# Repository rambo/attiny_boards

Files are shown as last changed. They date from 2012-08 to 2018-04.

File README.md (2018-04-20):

View this project on [CADLAB.io](https://cadlab.io/node/904). 

# ATTiny breakout boards

Collection of various more or less prototype board designs for breaking
out SMD ATTinys.

The SMD parts are cheaper than DIP and I've grown tired of drilling holes
anyway, besides this way I can add some essential supporting hardware like
bypass caps and the ISP header on the same board (optionally also xtal)

Arduino support for these chips is available from the [arduino-tiny](https://github.com/rambo/arduino-tiny) project, 
see also [this tutorial](http://hlt.media.mit.edu/?p=1695) by High-Low Tech.

I personally have found using the ArduinoISP a bit hit-and-miss, so I suggest investing on a proper ISP (some of the clones work better
than others but I decided to get a genuine AVRISPmkII after spending an evening battling with ArduinoISP)

## The designs

  - attiny85_bo_1l.brd: this is a very quick design for ATTiny25/45/85 chips meant to be etched at home, thus in one layer. [Picture](https://picasaweb.google.com/lh/photo/0eMphjL9Uqn8iMIKu49FZNMTjNZETYmyPJy0liipFm0?feat=directlink).
  - attiny85_bo.brd: A two-layer design for ATTiny25/45/85 chips that should be generally quite usable. [Picture](https://picasaweb.google.com/lh/photo/wWMrBrGMo7IKX4xKiI6fBtMTjNZETYmyPJy0liipFm0?feat=directlink).
    - First revisions of the board had a silkscreen error, PB1 and PB2 were reversed (my bad).
    - For some reason the very first revision has much nicer silkscreen than the next, they were (likely) manufactured in different batches but I should doublecheck line widths etc.
  - attiny4313_bo.brd: A two-layer design (with a lot of vias so not really doable at home).
    - Got the boards, silkscreen is fine on these, [picture](https://picasaweb.google.com/lh/photo/29UdsFFLtWyybYlaUJ8i69MTjNZETYmyPJy0liipFm0?feat=directlink).
  - attiny84_bo.brd: A two-layer design that should be generally quite usable.
    - Got the boards, silkscreen is fine on these, [picture](https://picasaweb.google.com/lh/photo/29UdsFFLtWyybYlaUJ8i69MTjNZETYmyPJy0liipFm0?feat=directlink).
  - attiny1634_bo.brd: First revision of this board/schematic had a bug in the part definition. Thus a [trace must be cut](https://picasaweb.google.com/lh/photo/p4AA6TQTbEzGxg4LxbUNLtMTjNZETYmyPJy0liipFm0?feat=directlink) and a jumper wire added.
    - arduino-tiny support for this chip is still [experimental](https://github.com/rambo/arduino-tiny/tree/attiny1634)
  - attiny85_pogo_pgm.brd: an attempt to make a pogo-pin programming header that connects directly to ATTiny85 (SOIC) feet.
    - This proved to be rather misguided, it will require very carefull alignment rig but if I get the need of mass programming unsoldered chips I might still do it.

## TODO

  - Add diodes to protect against reverse and over -voltage (with indicator led ?)
  - simple board to break the ISP header into normal 2.54mm pitch pogo-pins in the same order (those pins unfortunately do not fit)
    into the cable connector directly), did this on stripboard and then realized dotboard would have been much better.

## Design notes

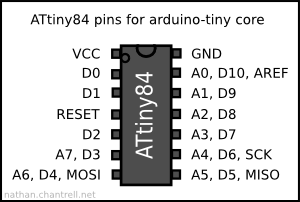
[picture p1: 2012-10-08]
attiny84_arduino_pins.png

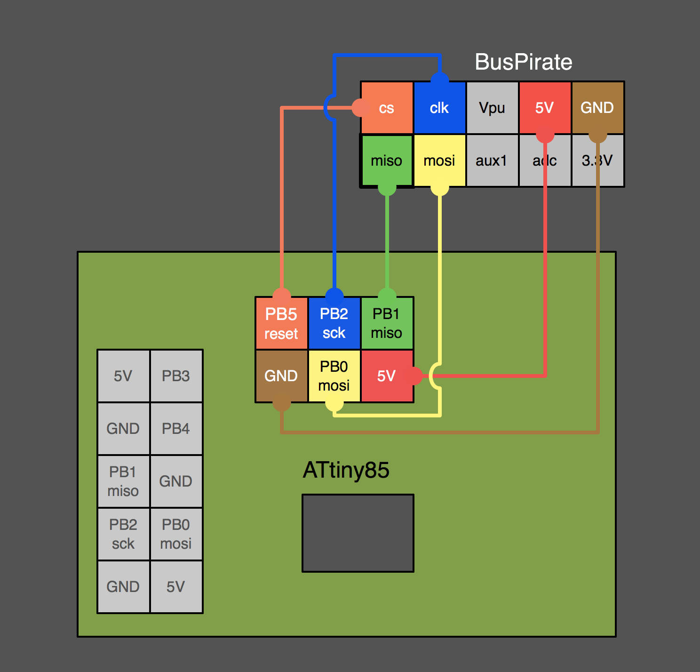
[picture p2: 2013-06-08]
buspirate_as_isp.png

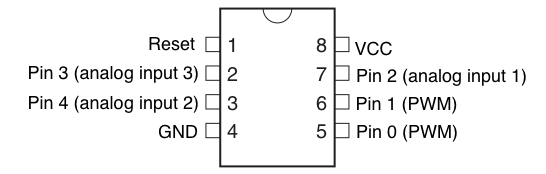
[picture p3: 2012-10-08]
attiny85_arduino_pins.png

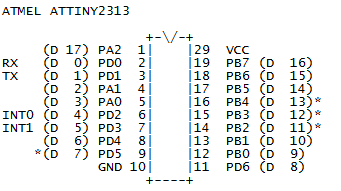
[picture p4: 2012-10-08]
attiny2313_arduino_pins.png

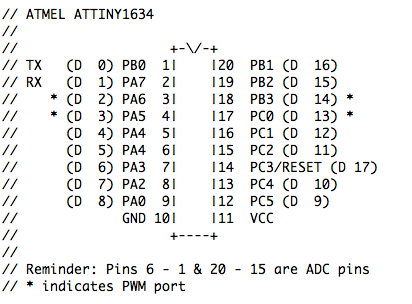
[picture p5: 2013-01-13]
attiny1634_arduino_pins.png

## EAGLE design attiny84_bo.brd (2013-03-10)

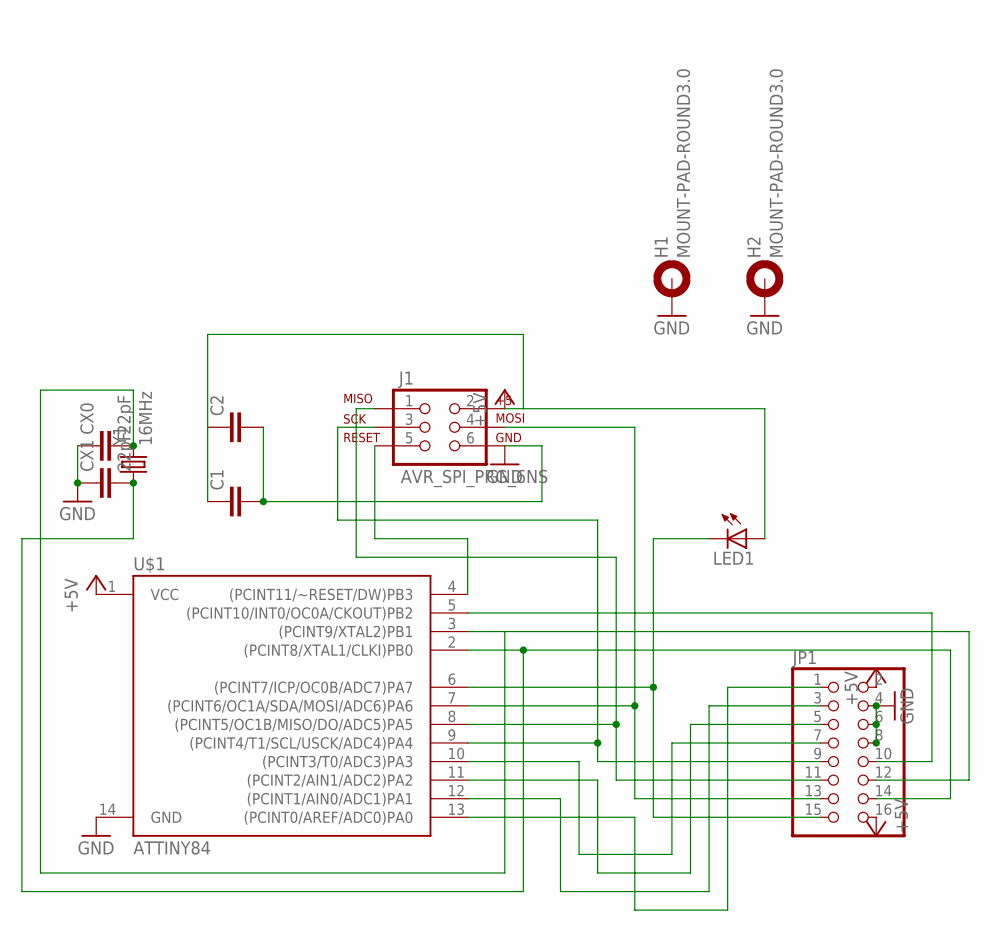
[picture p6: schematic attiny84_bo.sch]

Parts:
C1, C2: C-EUC0805; C0805
CX0, CX1: 22pF; C0603
H1, H2: MOUNT-PAD-ROUND3.0; 3,0-PAD
J1: AVR_SPI_PRG_6NS; 2X3-NS
JP1: PINHD-2X8; 2X08
LED1: LED0603; LED-0603
U$1: ATTINY84; SO14
Y1: 16MHz; CRYSTAL-SMD-5X3

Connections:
+5V: C1.1, C2.1, J1.2, JP1.2, JP1.16, LED1.A, U$1.1 (VCC)
GND: C1.2, C2.2, CX0.1, CX1.1, H1.B3,0, H2.B3,0, J1.6, JP1.4, JP1.6, JP1.8, U$1.14 (GND)
PA0: JP1.1, U$1.13 ((PCINT0/AREF/ADC0)PA0)
PA1: JP1.3, U$1.12 ((PCINT1/AIN0/ADC1)PA1)
PA2: JP1.5, U$1.11 ((PCINT2/AIN1/ADC2)PA2)
PA3: JP1.7, U$1.10 ((PCINT3/T0/ADC3)PA3)
PA4/SCL: J1.3, JP1.9, U$1.9 ((PCINT4/T1/SCL/USCK/ADC4)PA4)
PA5/MISO: J1.1, JP1.11, U$1.8 ((PCINT5/OC1B/MISO/DO/ADC5)PA5)
PA6/MOSI: J1.4, JP1.13, U$1.7 ((PCINT6/OC1A/SDA/MOSI/ADC6)PA6)
PA7: JP1.15, LED1.C, U$1.6 ((PCINT7/ICP/OC0B/ADC7)PA7)
PB0/XTAL1: CX1.2, JP1.14, U$1.2 ((PCINT8/XTAL1/CLKI)PB0), Y1.1
PB1/XTAL2: CX0.2, JP1.12, U$1.3 ((PCINT9/XTAL2)PB1), Y1.3 (2)
PB2: JP1.10, U$1.5 ((PCINT10/INT0/OC0A/CKOUT)PB2)
PB3/RESET-: J1.5, U$1.4 ((PCINT11/~RESET/DW)PB3)

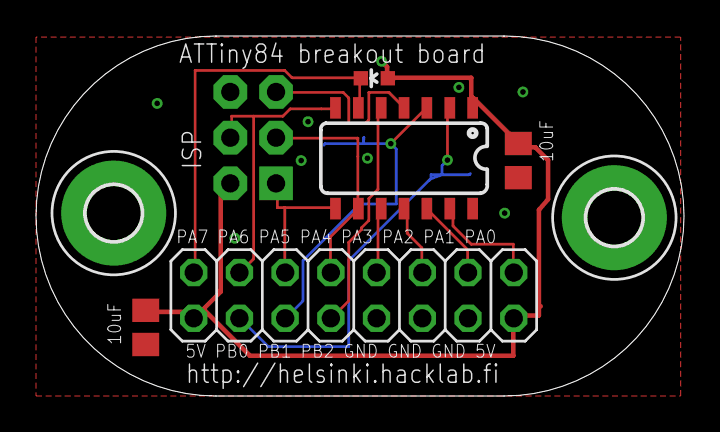
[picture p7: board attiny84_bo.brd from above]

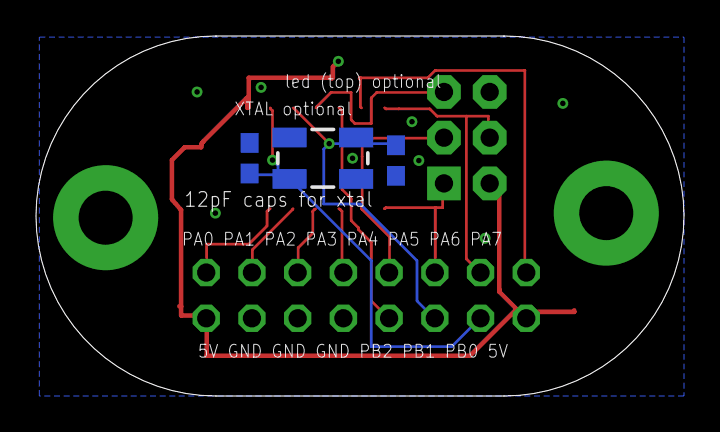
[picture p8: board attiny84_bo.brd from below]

Board: 2 copper layers, 36.0 x 20.0 mm, 11 parts (3 on the bottom side), 14 nets.

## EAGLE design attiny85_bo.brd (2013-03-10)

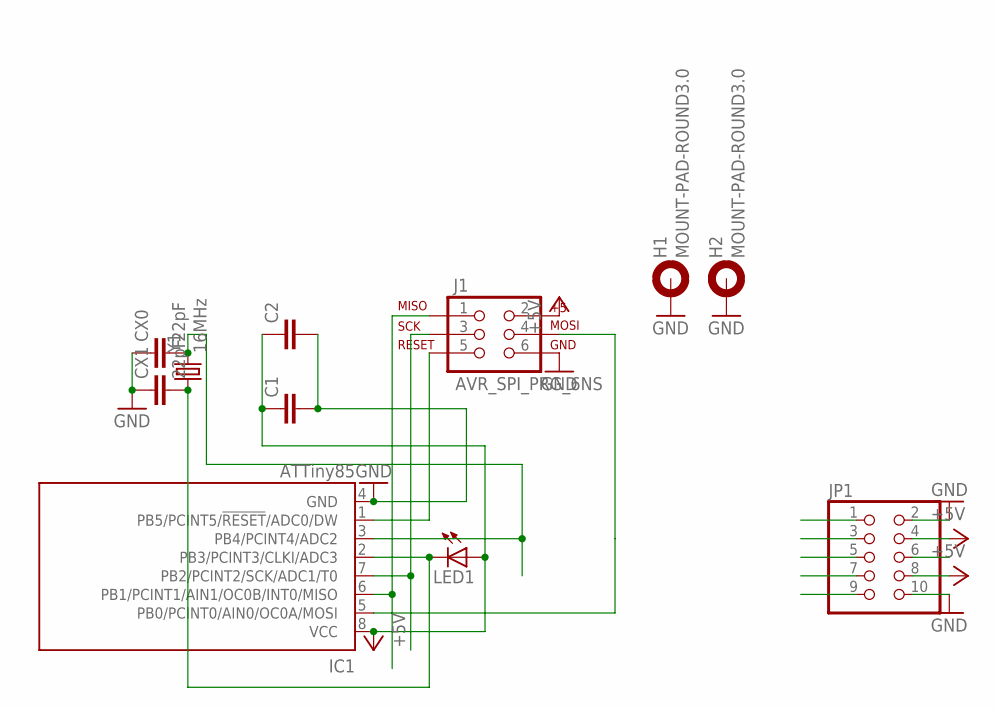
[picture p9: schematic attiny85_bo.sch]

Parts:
C1, C2: C-EUC0805; C0805
CX0, CX1: 22pF; C0603
H1, H2: MOUNT-PAD-ROUND3.0; 3,0-PAD
IC1: ATTiny85; 8S2
J1: AVR_SPI_PRG_6NS; 2X3-NS
JP1: PINHD-2X5; 2X05
LED1: LED0603; LED-0603
Y1: 16MHz; CRYSTAL-SMD-5X3

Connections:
+5V: C1.1, C2.1, IC1.8 (VCC), J1.2, JP1.4, JP1.8, LED1.A
GND: C1.2, C2.2, CX0.1, CX1.1, H1.B3,0, H2.B3,0, IC1.4 (GND), J1.6, JP1.2, JP1.10
PB0: IC1.5 (PB0/PCINT0/AIN0/OC0A/MOSI), J1.4, JP1.1
PB1: IC1.6 (PB1/PCINT1/AIN1/OC0B/INT0/MISO), J1.1, JP1.3
PB2: IC1.7 (PB2/PCINT2/SCK/ADC1/T0), J1.3, JP1.5
PB3: CX1.2, IC1.2 (PB3/PCINT3/CLKI/ADC3), JP1.7, LED1.C, Y1.1
PB4: CX0.2, IC1.3 (PB4/PCINT4/ADC2), JP1.9, Y1.3 (2)
PB5: IC1.1 (PB5/PCINT5/!RESET!/ADC0/DW), J1.5, JP1.6

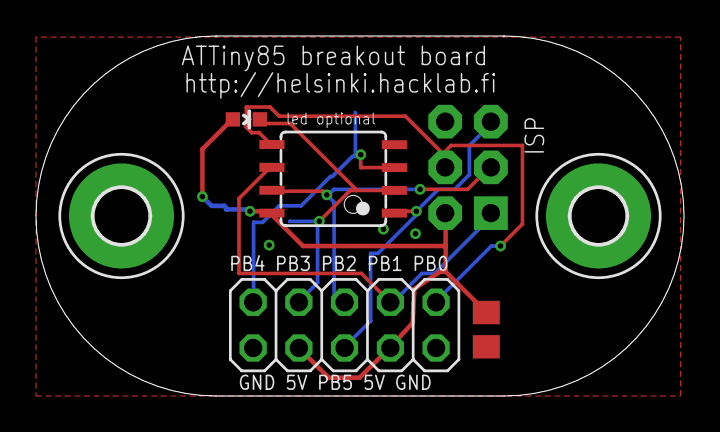
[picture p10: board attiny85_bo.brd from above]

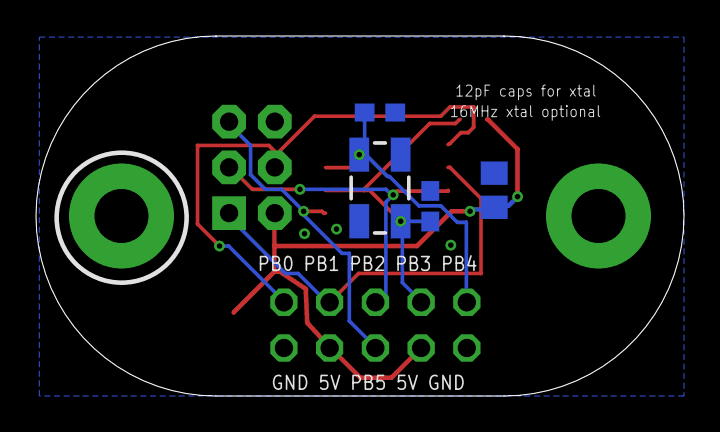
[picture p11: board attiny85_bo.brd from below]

Board: 2 copper layers, 36.0 x 20.0 mm, 11 parts (4 on the bottom side), 8 nets.

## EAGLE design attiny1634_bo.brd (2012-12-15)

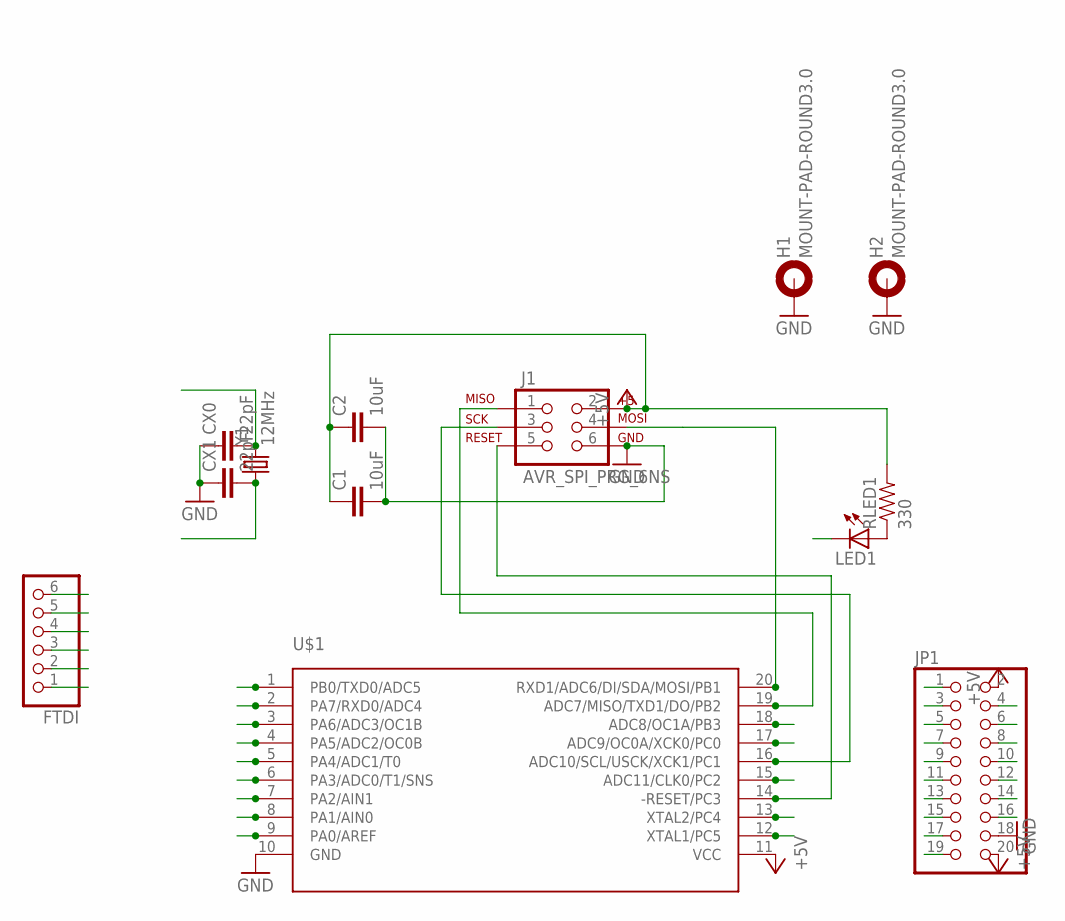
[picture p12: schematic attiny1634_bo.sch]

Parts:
C1, C2: 10uF; C0805
CX0, CX1: 22pF; C0603
FTDI: PINHD-1X6; 1X06
H1, H2: MOUNT-PAD-ROUND3.0; 3,0-PAD
J1: AVR_SPI_PRG_6NS; 2X3-NS
JP1: PINHD-2X10; 2X10
LED1: LED0603; LED-0603
RLED1: 330; 0603-RES
U$1: ATTINY1634; SOIC20
Y1: 12MHz; CRYSTAL-SMD-5X3

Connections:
+5V: C1.1, C2.1, FTDI.3, J1.2, JP1.2, JP1.20, RLED1.2, U$1.11 (VCC)
CTS: FTDI.2
GND: C1.2, C2.2, CX0.1, CX1.1, FTDI.1, H1.B3,0, H2.B3,0, J1.6, JP1.18, U$1.10 (GND)
unnamed: LED1.A, RLED1.1
PA0: JP1.5, U$1.9 (PA0/AREF)
PA1: JP1.7, U$1.8 (PA1/AIN0)
PA2: JP1.9, U$1.7 (PA2/AIN1)
PA3: JP1.11, U$1.6 (PA3/ADC0/T1/SNS)
PA4: JP1.13, U$1.5 (PA4/ADC1/T0)
PA5: JP1.15, U$1.4 (PA5/ADC2/OC0B)
PA6: JP1.17, U$1.3 (PA6/ADC3/OC1B)
PA7/RX0: FTDI.4, JP1.19, U$1.2 (PA7/RXD0/ADC4)
PB0/TXD0: FTDI.5, JP1.16, U$1.1 (PB0/TXD0/ADC5)
PB1/MOSI/ADC6: J1.4, JP1.14, U$1.20 (RXD1/ADC6/DI/SDA/MOSI/PB1)
PB2/ADC7/TX1: J1.1, JP1.12, U$1.19 (ADC7/MISO/TXD1/DO/PB2)
PB3/ADC8/OC1A: JP1.10, U$1.18 (ADC8/OC1A/PB3)
PC0/ADC9/OC0A: JP1.8, LED1.C, U$1.17 (ADC9/OC0A/XCK0/PC0)
PC1/SCL/ADC10: J1.3, JP1.1, U$1.16 (ADC10/SCL/USCK/XCK1/PC1)
PC2/ADC11: JP1.3, U$1.15 (ADC11/CLK0/PC2)
PC3/-RESET: FTDI.6, J1.5, U$1.14 (-RESET/PC3)
PC4/XTAL2: CX0.2, JP1.6, U$1.13 (XTAL2/PC4), Y1.3 (2)
PC5/XTAL1: CX1.2, JP1.4, U$1.12 (XTAL1/PC5), Y1.1

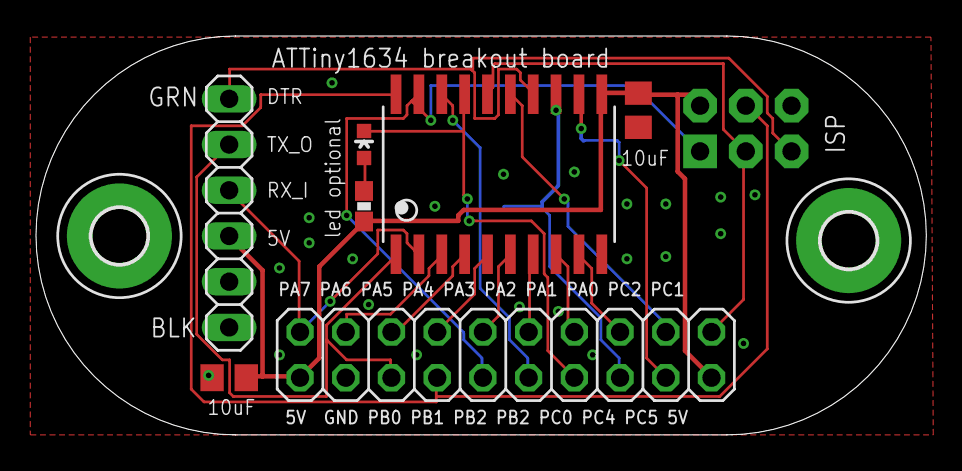
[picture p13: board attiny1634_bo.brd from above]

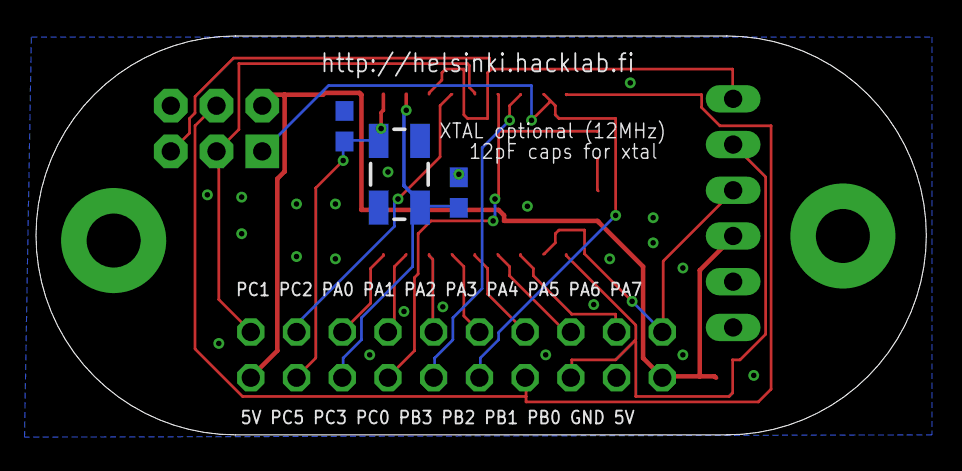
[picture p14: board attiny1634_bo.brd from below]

Board: 2 copper layers, 49.5 x 22.2 mm, 13 parts (3 on the bottom side), 21 nets.

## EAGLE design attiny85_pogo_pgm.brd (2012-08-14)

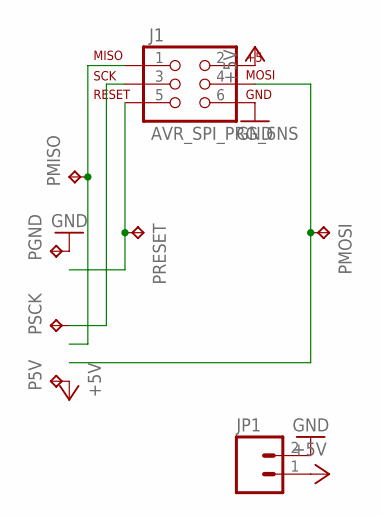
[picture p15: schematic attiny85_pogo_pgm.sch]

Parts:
J1: AVR_SPI_PRG_6NS; 2X3-NS
JP1: M02PTH; 1X02
P5V: TPTP12R; TP12R
PGND: TPTP12R; TP12R
PMISO: TPTP12R; TP12R
PMOSI: TPTP12R; TP12R
PRESET: TPTP12R; TP12R
PSCK: TPTP12R; TP12R

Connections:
+5V: J1.2, JP1.1, P5V.TP
GND: J1.6, JP1.2, PGND.TP
IN1/MISO: J1.1, PMISO.TP
RESET-: J1.5, PRESET.TP
SCL/SCK: J1.3, PSCK.TP
SDA/MOSI: J1.4, PMOSI.TP

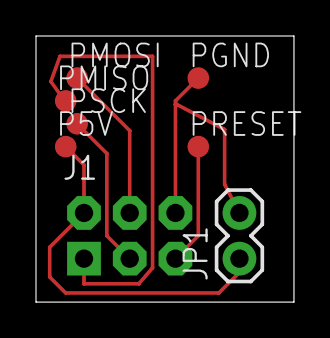
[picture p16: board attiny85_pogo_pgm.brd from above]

Board: 1 copper layer, 14.3 x 14.8 mm, 8 parts (0 on the bottom side), 6 nets.

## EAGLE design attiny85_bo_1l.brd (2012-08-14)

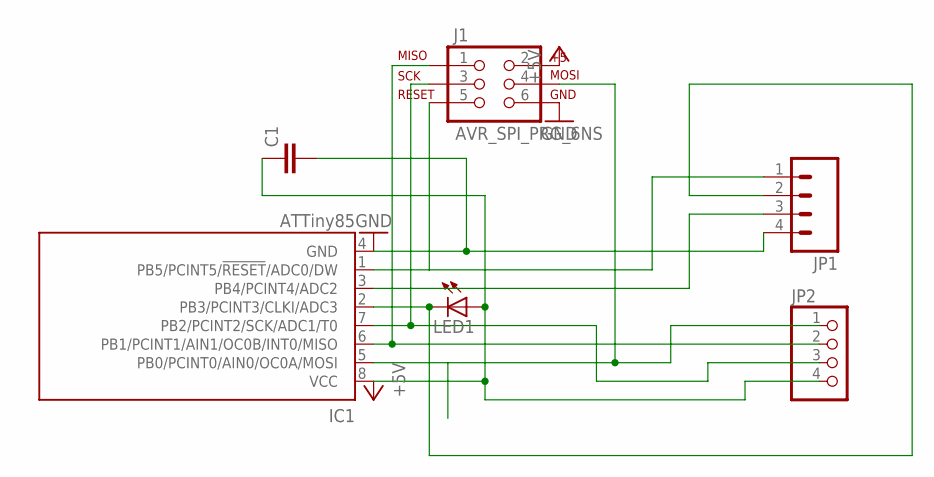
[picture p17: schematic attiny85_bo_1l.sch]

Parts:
C1: C-EUC0805; C0805
IC1: ATTiny85; 8S2
J1: AVR_SPI_PRG_6NS; 2X3-NS
JP1: M041X04_NO_SILK; 1X04_NO_SILK
JP2: PINHD-1X4; 1X04
LED1: LED0603; LED-0603

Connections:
+5V: C1.1, IC1.8 (VCC), J1.2, JP2.4, LED1.A
GND: C1.2, IC1.4 (GND), J1.6, JP1.4
IN1/MISO: IC1.6 (PB1/PCINT1/AIN1/OC0B/INT0/MISO), J1.1, JP2.2
unnamed: IC1.3 (PB4/PCINT4/ADC2), JP1.3
unnamed: IC1.2 (PB3/PCINT3/CLKI/ADC3), JP1.2, LED1.C
unnamed: IC1.1 (PB5/PCINT5/!RESET!/ADC0/DW), J1.5, JP1.1
SCL/SCK: IC1.7 (PB2/PCINT2/SCK/ADC1/T0), J1.3, JP2.3
SDA/MOSI: IC1.5 (PB0/PCINT0/AIN0/OC0A/MOSI), J1.4, JP2.1


Board: 1 copper layer, 19.3 x 20.0 mm, 6 parts (0 on the bottom side), 8 nets.

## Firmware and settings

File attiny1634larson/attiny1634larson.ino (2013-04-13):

/*
  Blink
  Turns on an LED on for one second, then off for one second, repeatedly.
 
  This example code is in the public domain.
 */

// the setup routine runs once when you press reset:
void setup() {                
  // initialize the digital pin as an output.
  for (byte led = 0; led<8; led++)
  {
      pinMode(led, OUTPUT);
      digitalWrite(led, LOW);   
  }
}

// the loop routine runs over and over again forever:
void loop()
{
  byte led;
  byte prevled;
  byte otherend;
  byte prevotherend;
  for (led = 0; led<8; led++)
  {
      if (led > 0)
      {
          prevled = led - 1;
      }
      otherend = 7-led;
      prevotherend = otherend+1;
      digitalWrite(prevled, LOW);
      digitalWrite(prevotherend, LOW);
      
      digitalWrite(led, HIGH);
      digitalWrite(otherend, HIGH);
      delay(100);
  }
  digitalWrite(led-1, LOW);
  digitalWrite(otherend, LOW);
  delay(1000);
  
}

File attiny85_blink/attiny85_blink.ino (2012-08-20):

/**
 * Pin notes by Suovula (see also http://hlt.media.mit.edu/?p=1229)
 *
// I2C
arduino pin 0 = not(OC1A) = PORTB <- _BV(0) = SOIC pin 5 (I2C SDA, PWM)
arduino pin 2 =           = PORTB <- _BV(2) = SOIC pin 7 (I2C SCL, Analog 1)
// Timer1 -> PWM
arduino pin 1 =     OC1A  = PORTB <- _BV(1) = SOIC pin 6 (PWM)
arduino pin 3 = not(OC1B) = PORTB <- _BV(3) = SOIC pin 2 (Analog 3, XTAL)
arduino pin 4 =     OC1B  = PORTB <- _BV(4) = SOIC pin 3 (Analog 2, XTAL)
 */

#define BLINKPIN 3 // Note: if you have xtal you can't use this as output

void setup()
{
    // TODO: Tri-state this and wait for input voltage to stabilize 
    pinMode(BLINKPIN, OUTPUT); // OC1B-, Arduino pin 3, ADC
    digitalWrite(BLINKPIN, LOW); // Note that this makes the led turn on, it's wire this way to allow for the voltage sensing above.
    
    // Whatever other setup routines ?
    
    digitalWrite(BLINKPIN, HIGH);
}

void loop()
{
    digitalWrite(BLINKPIN, LOW); // Note that this makes the led turn on, it's wire this way to allow for the voltage sensing above.
    delay(500);
    digitalWrite(BLINKPIN, HIGH);
    delay(500);
}

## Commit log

2012-08-14 simple breakout board for attiny25/45/85
    [attiny_bo_1l.brd, attiny_bo_1l.sch]
2012-08-14 name to reflect correct chip
    [attiny85_bo_1l.brd, attiny85_bo_1l.sch]
2012-08-14 attempt to make a programming header that connects to soic attiny85 pins with pogo-pins (in retrospect a clip would probably work better...)
    [attiny85_pogo_pgm.brd, attiny85_pogo_pgm.sch]
2012-08-14 a much nicer design, I have a set of these on their way from Seeed
    [attiny85_bo.brd, attiny85_bo.sch]
2012-08-14 descriptions of the boards to the README
2012-08-14 mark the chip type to the text
    [attiny85_bo.brd]
2012-08-14 started working on attiny84 breakout board
    [attiny84_bo.brd, attiny84_bo.sch]
2012-08-14 initial placement
    [attiny84_bo.brd, attiny84_bo.sch]
2012-08-14 routing settings
    [attiny84_bo.brd]
2012-08-14 signal names
    [attiny84_bo.brd, attiny84_bo.sch]
2012-08-14 second 5v input
    [attiny84_bo.brd, attiny84_bo.sch]
2012-08-14 pin legend
    [attiny84_bo.brd]
2012-08-14 some labels
    [attiny84_bo.brd]
2012-08-14 typo fix
    [attiny84_bo.brd]
2012-08-14 xtal xap size
    [attiny84_bo.brd]
2012-08-14 move the other cap near the other 5v input
    [attiny84_bo.brd]
2012-08-14 started working on attiny4313 version
    [attiny4313_bo.brd, attiny4313_bo.sch]
2012-08-14 signals v1, probably bad
    [attiny4313_bo.brd, attiny4313_bo.sch]
2012-08-14 pin identifiers
    [attiny4313_bo.brd, attiny4313_bo.sch]
2012-08-14 minor adjustments
    [attiny4313_bo.brd]
2012-08-18 protection diodes might be a good idea...
2012-08-18 pb1/2 were reversed on silkscreen
    [attiny85_bo.brd]
2012-08-18 trivial sketch to blink the led on the attiny85 boards
2012-08-18 silkscreen fix and adjusted readme
    [attiny84_bo.brd]
2012-08-18 clearer markings for the first pins
    [attiny4313_bo.brd, attiny84_bo.brd, attiny85_bo.brd]
2012-09-01 photos of the new boards
2012-09-01 notes on arduino support
2012-10-08 pin mappings
2012-11-12 copy the 4313 as base for this breakout
    [attiny1634_bo.brd, attiny1634_bo.sch]
2012-11-12 use the new part and remove old wires from schematic
    [attiny1634_bo.brd, attiny1634_bo.sch]
2012-11-12 12MHz max speed for this part
    [attiny1634_bo.brd, attiny1634_bo.sch]
2012-11-12 ripup the traces, needs to be rerouted anyway
    [attiny1634_bo.brd]
2012-11-12 minor fixes to the lib, connected programming signals and xtal
    [attiny1634_bo.brd, attiny1634_bo.sch]
2012-11-12 connected portA
    [attiny1634_bo.brd, attiny1634_bo.sch]
2012-11-12 typo fixes, connected portB
    [attiny1634_bo.brd, attiny1634_bo.sch]
2012-11-12 more signals
    [attiny1634_bo.brd, attiny1634_bo.sch]
2012-11-12 adjusted texts and positions
    [attiny1634_bo.brd, attiny1634_bo.sch]
2012-11-12 changed the board title
    [attiny1634_bo.brd]
2012-11-12 minor manual routing adjustment, I am not 100% happy with this though
    [attiny1634_bo.brd]
2012-11-12 adjusted xtal position
    [attiny1634_bo.brd]
2012-11-12 pre-routed the clock
    [attiny1634_bo.brd]
2012-11-12 freeroute.net autorouted (and some vias added)
    [attiny1634_bo.brd]
2012-11-12 moar GND
    [attiny1634_bo.brd]
2012-11-12 small adjustment for better isolation
    [attiny1634_bo.brd]
2012-11-12 I think it is now good enough
    [attiny1634_bo.brd]
2012-12-15 shite, the MOSI is was marked to wrong pin...
    [attiny1634_bo.brd, attiny1634_bo.sch]
2012-12-15 add a resistor for the led and move the mcu group right, in preparation for adding a uart header
    [attiny1634_bo.brd, attiny1634_bo.sch]
2012-12-15 space for cable
    [attiny1634_bo.brd, attiny1634_bo.sch]
2012-12-15 added Arduino style FTDI UART header
    [attiny1634_bo.brd, attiny1634_bo.sch]
2012-12-15 manually routed the xtal
    [attiny1634_bo.brd]
2012-12-15 Eagle autorouted
    [attiny1634_bo.brd]
2012-12-15 ignore stopmask warnigns
    [attiny1634_bo.brd]
2012-12-15 args, the PORTA pins did not get reconnected when I fixed the mcu part
    [attiny1634_bo.brd, attiny1634_bo.sch]
2012-12-15 re-routed the xtal
    [attiny1634_bo.brd]
2013-01-13 pin numers from core source comments
2013-03-10 remaking the attiny85 baord so it is more easily connected to stripboard via 90deg pin header
    [attiny85_bo.brd, attiny85_bo.sch]
2013-03-10 route the crystals manually
    [attiny85_bo.brd]
2013-03-10 let autorouter take care of the rest
    [attiny85_bo.brd]
2013-03-10 minor adjustment
    [attiny85_bo.brd]
2013-03-10 very quick and dirty prog header adjustment to attiny84 board
    [attiny84_bo.brd]

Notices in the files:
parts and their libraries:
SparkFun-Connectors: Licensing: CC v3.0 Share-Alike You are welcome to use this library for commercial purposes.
